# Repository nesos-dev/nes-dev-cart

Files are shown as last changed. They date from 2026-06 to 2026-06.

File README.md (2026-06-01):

# NES-DEV-CART

Open-source FPGA development cartridge for the Nintendo Entertainment System. **v4.1** — now with 8MB onboard PSRAM.

Plugs into a real NES. Programs over USB-C. Debug via UART. Full NES bus access. 39 SMT components, professionally assembled.

## What Is It

NES-DEV-CART is a cartridge-shaped PCB that replaces the ROM chip with a modern FPGA. It gives your FPGA bidirectional access to every signal on the NES 72-pin cartridge connector — CPU bus, PPU bus, CIC, expansion port — all level-shifted between 5V and 3.3V.

An onboard FT2232HL provides USB-C JTAG programming and UART debug console. No external programmer needed.

## Specs

| | |
|---|---|
| **FPGA** | Sipeed Tang Primer 25K (Gowin GW5A-25, 25K LUTs) |
| **ROM Storage** | 8MB SPI PSRAM |
| **USB** | FT2232HL — Ch.A: JTAG, Ch.B: UART debug |
| **Level Shifting** | 4x 74ALVC164245DGG (bidirectional 5V-3.3V) |
| **NES Signals** | CPU A0-A14, D0-D7, PPU A0-A13, D0-D7, CIC, IRQ, EXP |
| **PCB** | 4-layer, 1.6mm, ENIG, gold fingers, L-shaped |
| **Connector** | 72-pin NES edge connector (30-degree bevel) |
| **FPGA Connection** | 2x DF40C-60DS 0.4mm B2B connectors |

## What You Can Build

- **Homebrew games** — test on real hardware, not emulators
- **Custom mappers** — design mapper chips in Verilog that never existed
- **Flash cartridge** — load ROMs from USB, run on real NES
- **Bus analyzer** — sniff CPU/PPU traffic in real time via UART
- **Expansion audio** — VRC6, Sunsoft 5B style audio hardware
- **Hardware research** — study NES bus behavior at the signal level

## Repository Structure

```
hardware/
├── nes-dev-cart.kicad_pcb      KiCad PCB layout
├── nes-dev-cart.kicad_sch      KiCad schematic
├── nes-dev-cart.kicad_pro      KiCad project
├── footprints/                 Custom footprint libraries
├── shell/                     Cart shell STL files (front/back)
└── production/
    ├── nes-dev-cart-gerbers.zip    Fabrication-ready gerbers
    ├── nes-dev-cart-bom.csv        BOM with LCSC part numbers
    ├── nes-dev-cart-cpl-jlcpcb.csv Component placement list
    ├── README-assembly.md          Assembly instructions
    ├── nes-dev-cart-render-*.png   Board renders (top/bottom)
    └── gerbers/                    Individual gerber files

website/                        Product website (nesos.dev)
├── index.html
├── style.css
└── success.html
```

## Ordering PCBs

Upload `hardware/production/nes-dev-cart-gerbers.zip` to JLCPCB:

- Layers: 4
- Thickness: 1.6mm
- Surface finish: ENIG
- Gold fingers: Yes, 30-degree bevel
- Assembly: Both sides (DF40 connectors on bottom)

Upload `nes-dev-cart-bom.csv` and `nes-dev-cart-cpl-jlcpcb.csv` for SMT assembly. See `production/README-assembly.md` for details.

## Requirements

- NES front-loader console (NES-001)
- Sipeed Tang Primer 25K module
- USB-C cable
- Gowin IDE or Yosys/nextpnr for FPGA development

## License

Hardware: GPL-3.0

NES-DEV-CART is an independent project not affiliated with or endorsed by Nintendo.

## Links

- Website: https://nesos.dev

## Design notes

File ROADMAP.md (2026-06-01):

# NES-DEV-CART Roadmap

## Current Status: v4.0 — Hardware Complete

The PCB design is fabrication-ready. Gerbers, BOM, and assembly files are generated. DRC clean.

## v4.1 — SPI PSRAM (In Progress)

Adding 8MB SPI PSRAM for full ROM storage beyond the FPGA's internal block RAM.

### Hardware
- [ ] Add PSRAM to PCB
- [ ] Update gerbers
- [ ] Order prototype PCBs

### FPGA Firmware
- [ ] QSPI PSRAM controller
- [ ] NES bus interface (address decode, tristate data bus)
- [ ] NROM mapper (mapper 0)
- [ ] UxROM mapper (mapper 2)
- [ ] MMC1 mapper (mapper 1)
- [ ] MMC3 mapper (mapper 4)
- [ ] CIC bypass

### Host Software
- [ ] ROM upload via UART
- [ ] Debug console
- [ ] Bus analyzer
- [ ] JTAG programming

### Documentation
- [ ] Hardware pinout reference
- [ ] Signal timing diagrams
- [ ] Mapper development guide

## Timeline

| Milestone | Target |
|---|---|
| v4.1 hardware ordered | June 2026 |
| First game on real NES | July 2026 |
| Host tools + 4 mappers | August 2026 |
| Documentation + launch | September 2026 |

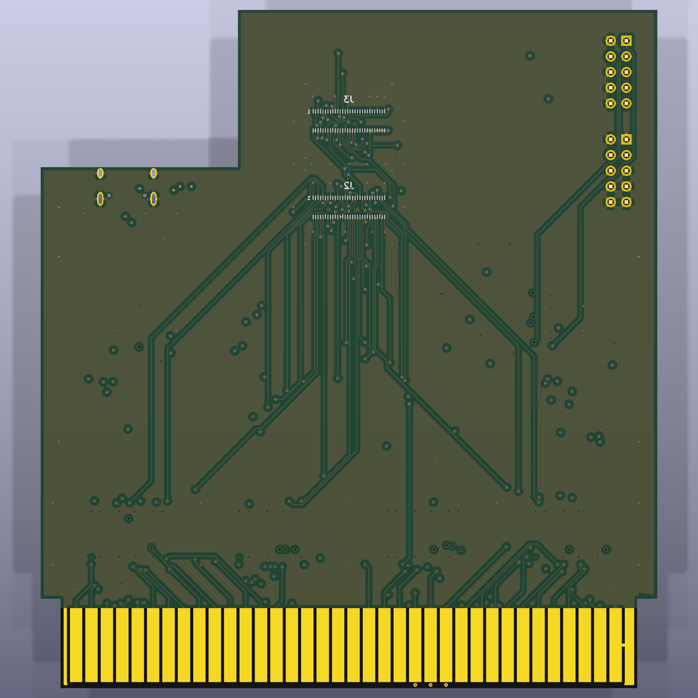
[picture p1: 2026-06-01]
hardware/production/nes-dev-cart-render-bottom.png

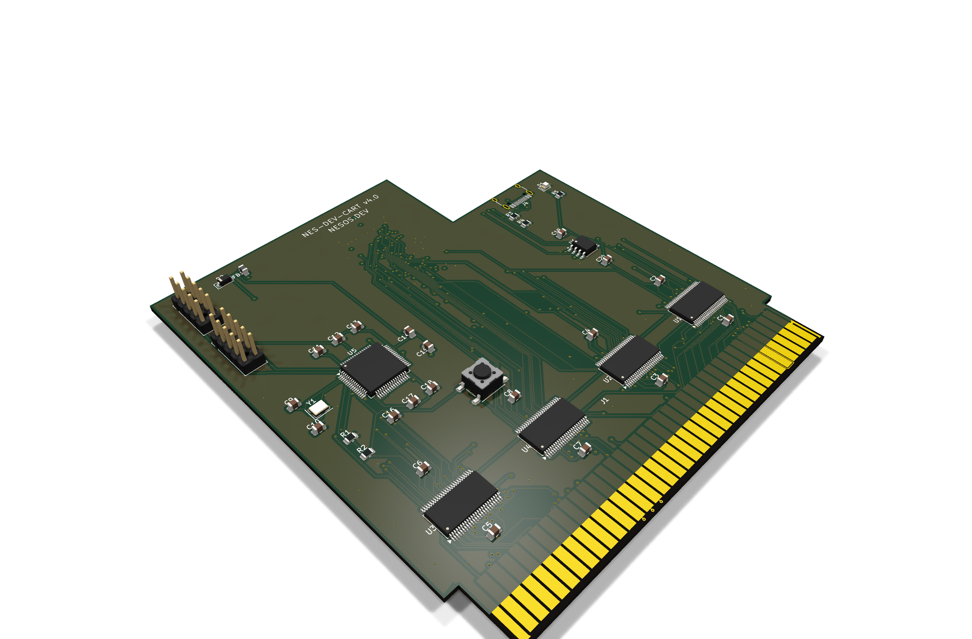
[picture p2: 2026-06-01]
hardware/production/nes-dev-cart-render-top-3d.png

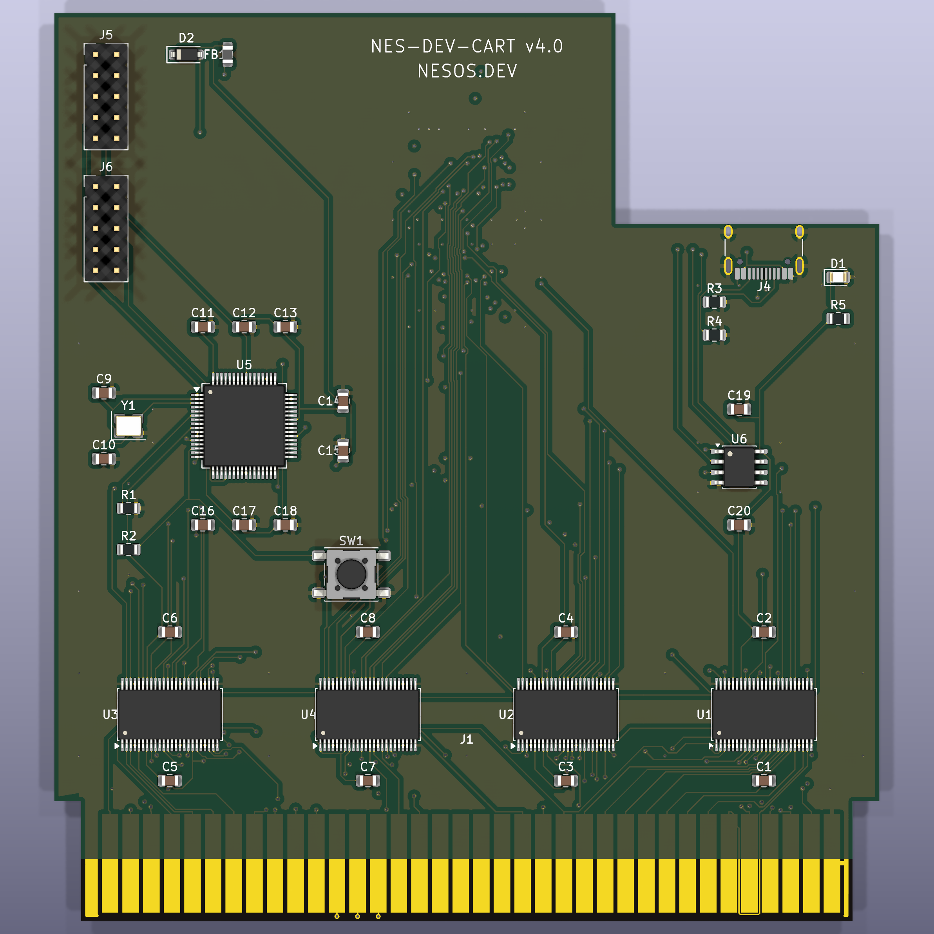
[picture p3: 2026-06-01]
hardware/production/nes-dev-cart-render-top.png

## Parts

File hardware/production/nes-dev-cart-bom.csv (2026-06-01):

Comment | Designator | Footprint | LCSC Part #
100nF 50V X7R | C1,C2,C3,C4,C5,C6,C7,C8,C11,C12,C13,C14,C16,C18,C19 | C_0805_2012Metric | C49678
27pF 50V NP0 | C9,C10 | C_0805_2012Metric | C107113
4.7uF 25V X5R | C15,C17 | C_0805_2012Metric | C1779
2.2k 1% | R1 | R_0805_2012Metric | C17520
10k 1% | R2 | R_0805_2012Metric | C17414
5.1k 1% | R3,R4 | R_0805_2012Metric | C27834
330R 1% | R5 | R_0805_2012Metric | C17630
74ALVC164245DGG | U1,U2,U3,U4 | TSSOP-48_6.1x12.5mm_P0.5mm | C5531
FT2232HL | U5 | LQFP-64_10x10mm_P0.5mm | C27882
12MHz Crystal | Y1 | Crystal_SMD_3225-4Pin_3.2x2.5mm | C390764
Ferrite 600R@100MHz | FB1 | L_0805_2012Metric | C21286
Green LED | D1 | LED_0805_2012Metric | C2297
1N5817W Schottky | D2 | D_SOD-123 | C571353
USB-C 16P Receptacle | J4 | USB_C_Receptacle_HRO_TYPE-C-31-M-12 | C165948
DF40C-60DS-0.4V(51) | J2,J3 | Hirose_DF40C-60DS-0.4V_2x30_P0.4mm | C597938
PTS645SM43SMTR92LFS | SW1 | SW_SPST_PTS645 | C221880
APS6404L-3SQR-SN 8MB PSRAM | U6 | SOIC-8_3.9x4.9mm_P1.27mm | C5333729
10uF 25V X5R | C20 | C_0805_2012Metric | C15850

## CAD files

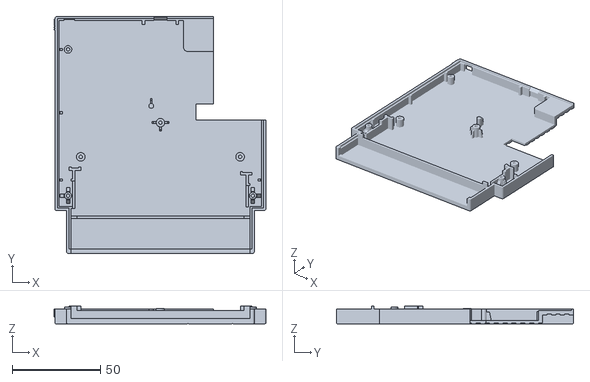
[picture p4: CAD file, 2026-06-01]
hardware/shell/dev_cart_front.stl
119.8 x 134.0 x 10.1

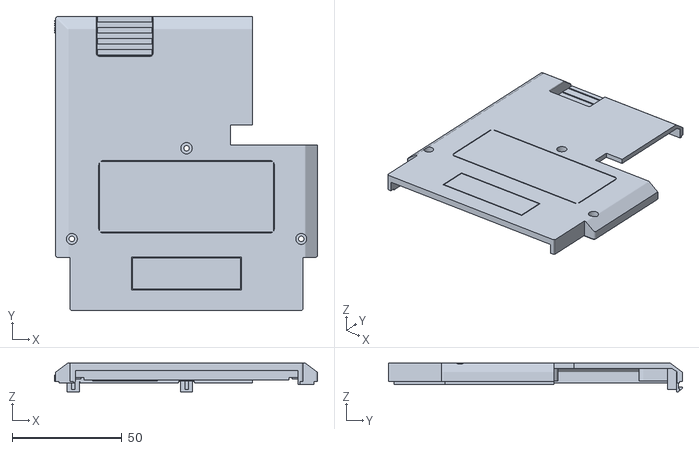
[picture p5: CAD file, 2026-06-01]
hardware/shell/dev_cart_back.stl
119.8 x 134.1 x 13.2

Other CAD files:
hardware/shell/dev_cart_v3.blend

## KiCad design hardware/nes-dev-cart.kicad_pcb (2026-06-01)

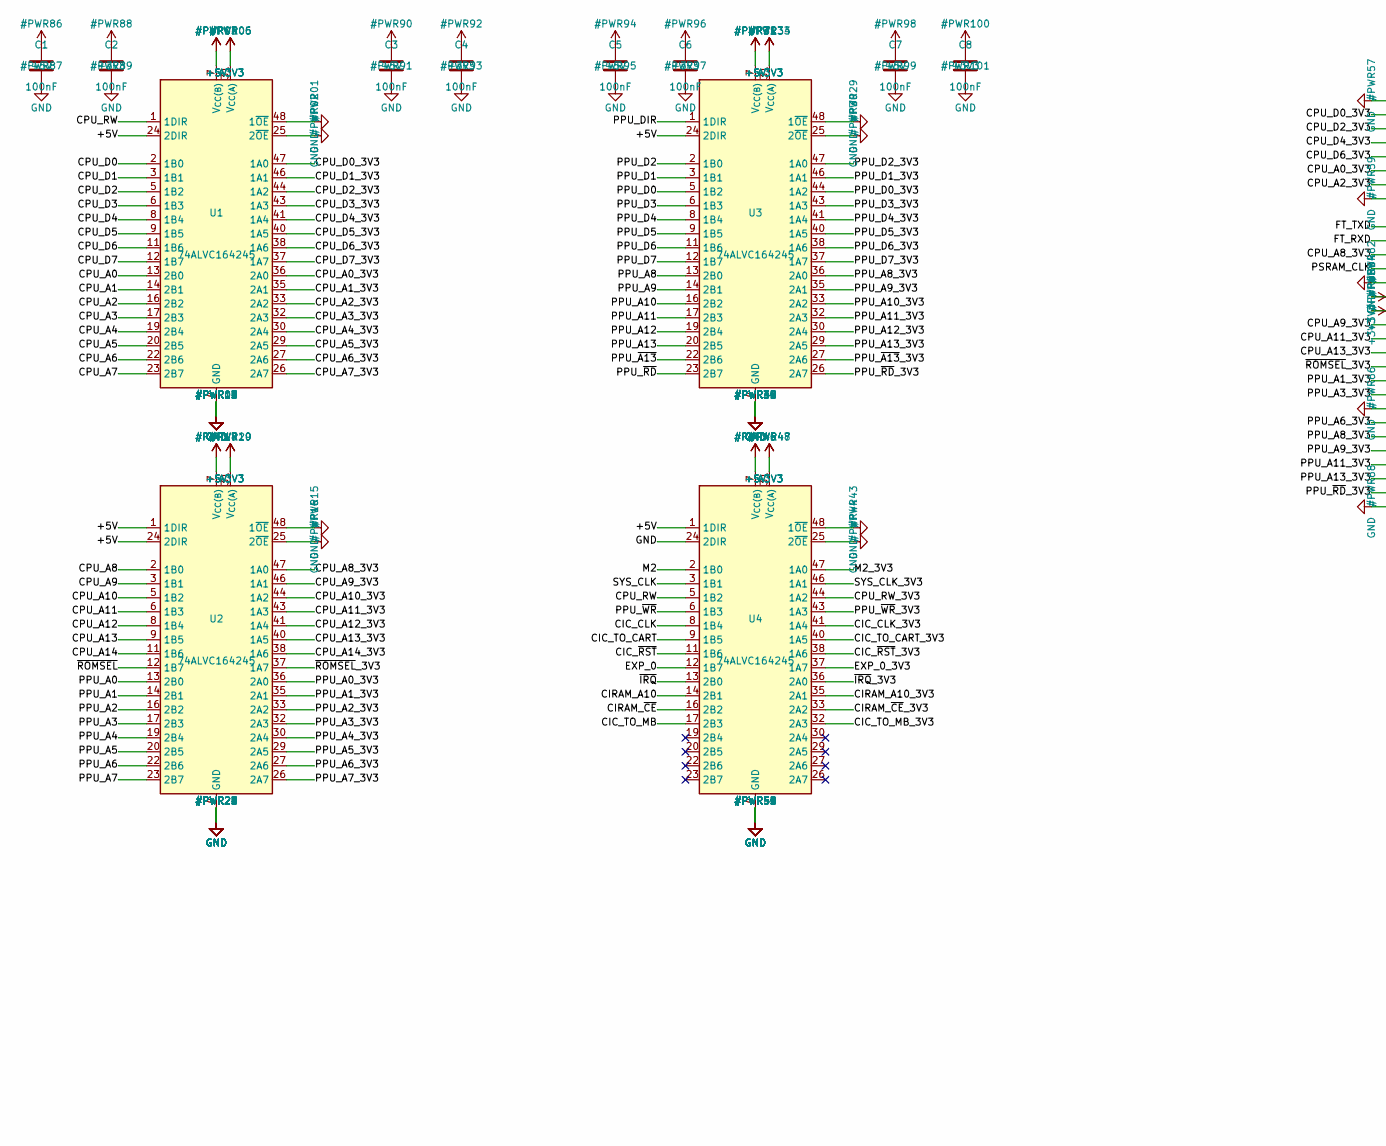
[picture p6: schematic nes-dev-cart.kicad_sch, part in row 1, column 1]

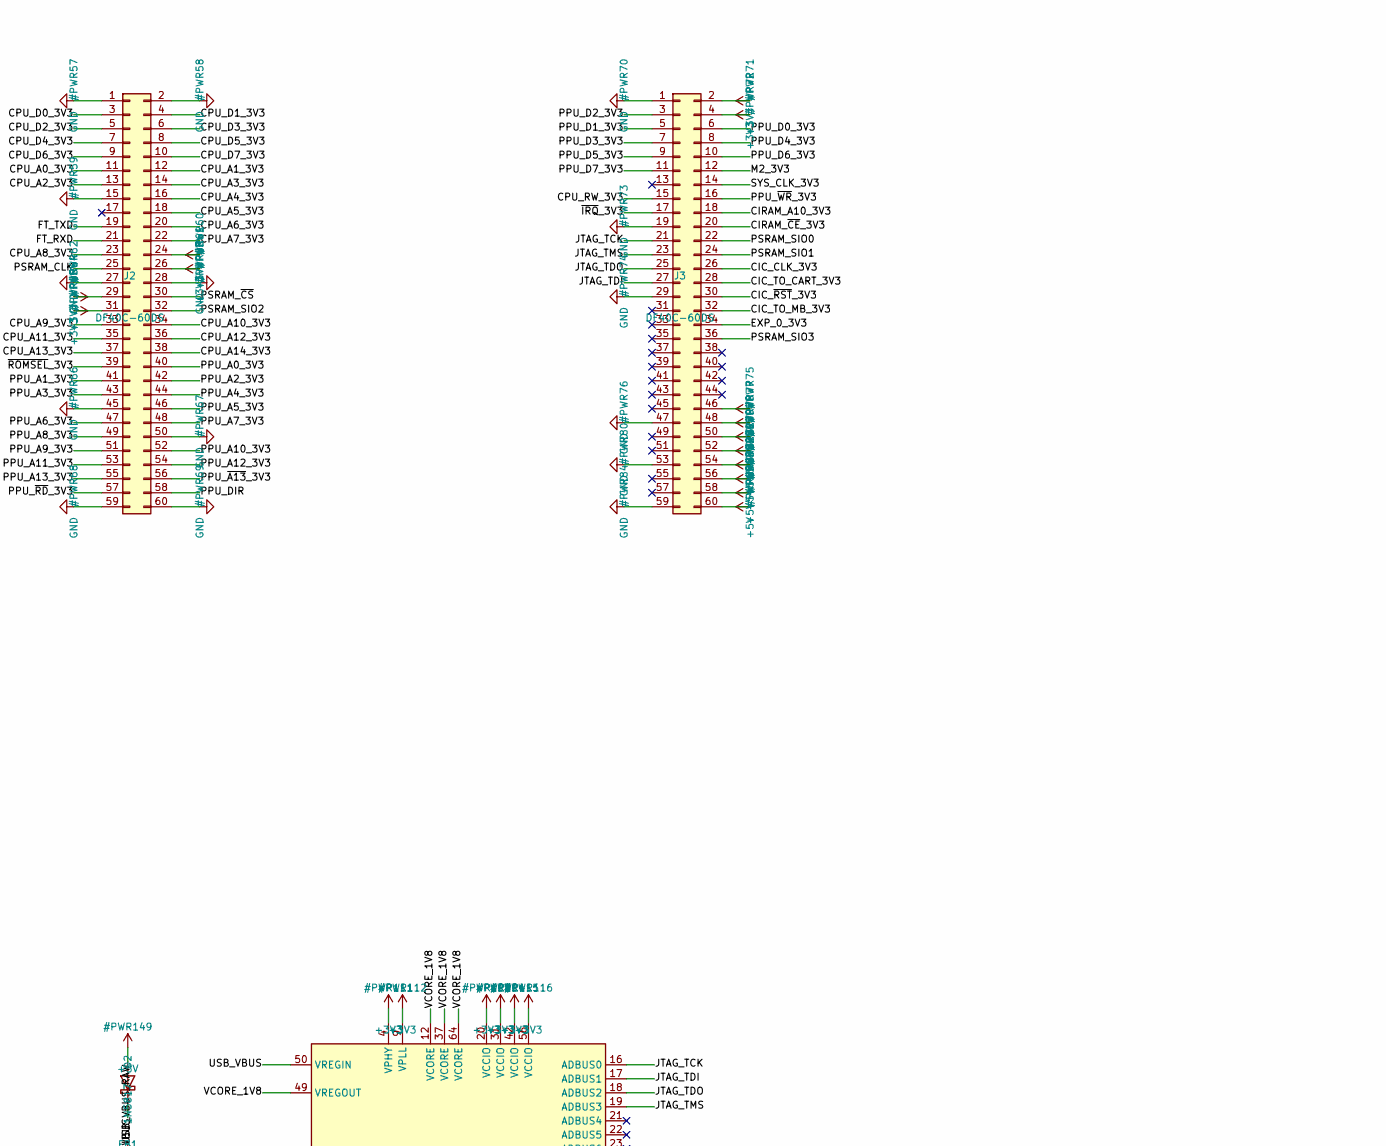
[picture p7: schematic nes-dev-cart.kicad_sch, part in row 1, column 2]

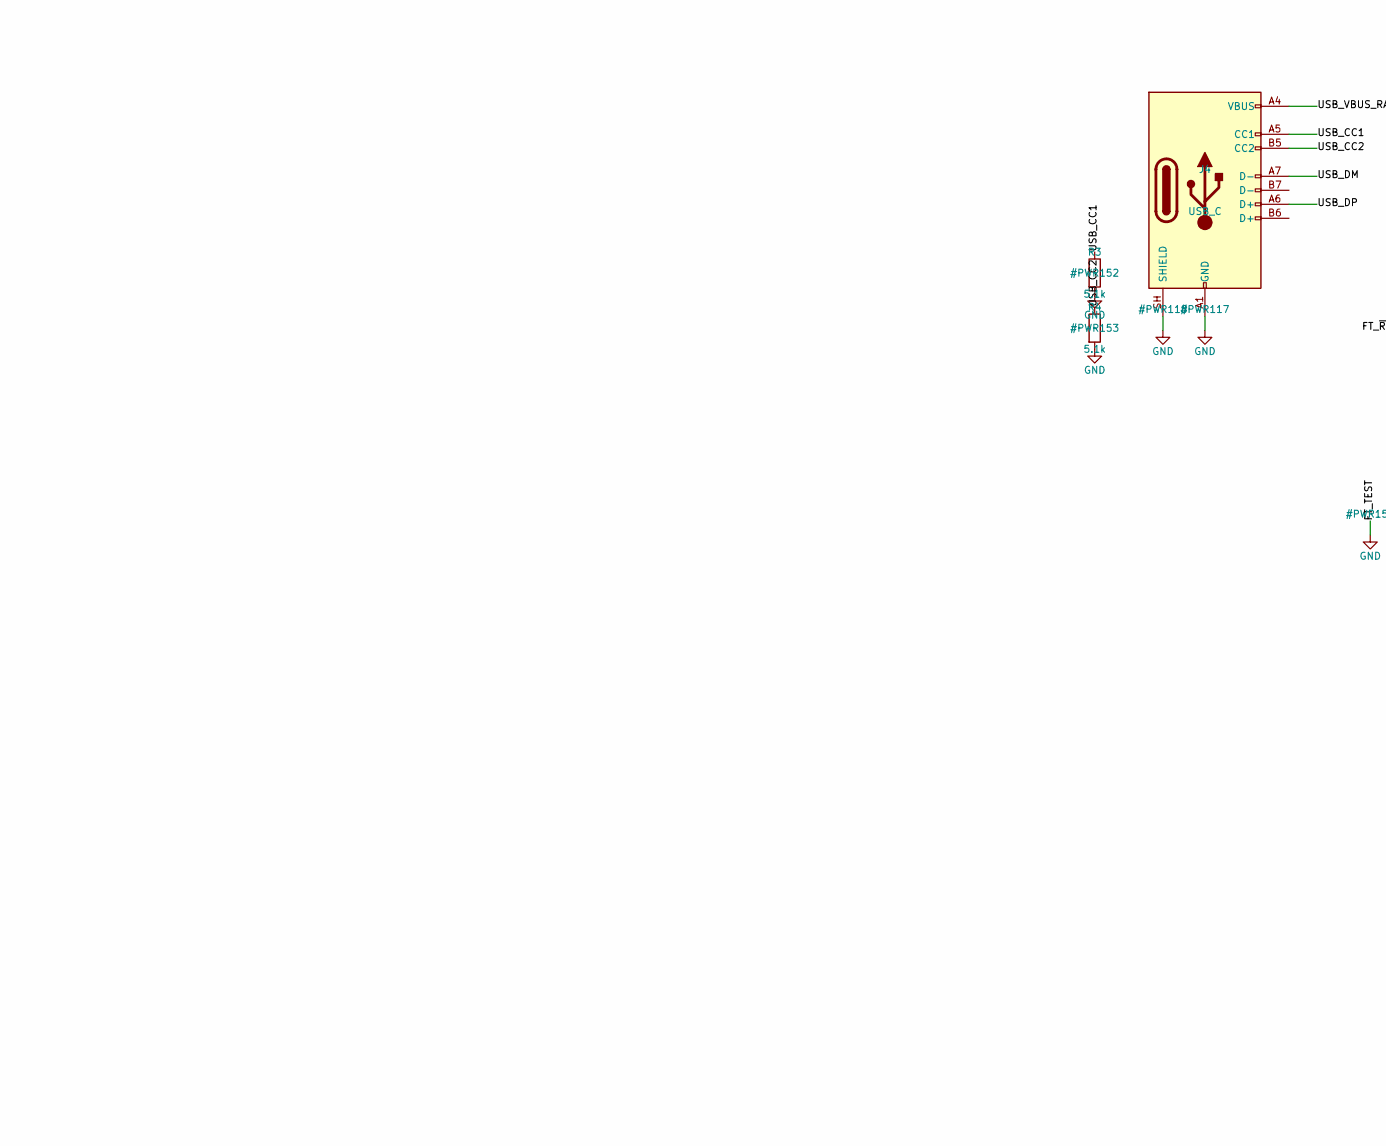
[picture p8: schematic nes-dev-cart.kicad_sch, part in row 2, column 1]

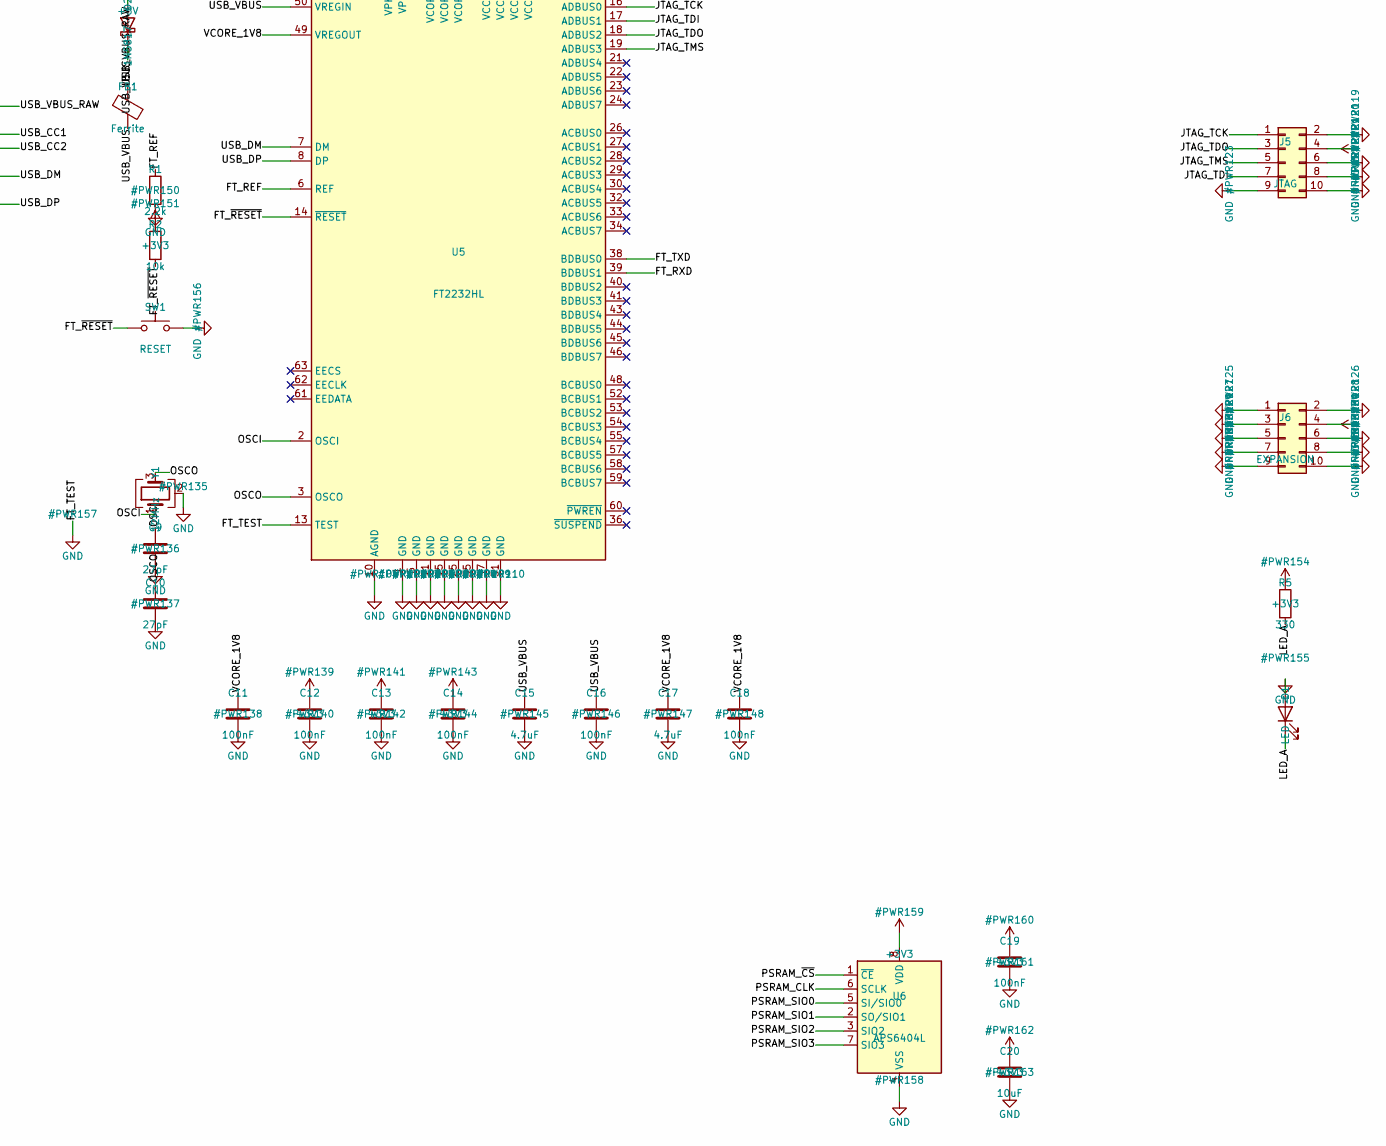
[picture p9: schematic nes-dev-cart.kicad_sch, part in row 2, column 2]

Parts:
C1, C2, C3, C4, C5, C6, C7, C8, C11, C12, C13, C14, C16, C18, C19: 100nF
C9, C10: 27pF
C15, C17: 4.7uF
C20: 10uF
D1: LED
D2: 1N5817
FB1: Ferrite
J2, J3: DF40C-60DS
J4: USB_C
J5: JTAG
J6: EXPANSION
R1: 2.2k
R2: 10k
R3, R4: 5.1k
R5: 330
SW1: RESET
U1, U2, U3, U4: 74ALVC164245
U5: FT2232HL
U6: APS6404L
Y1: 12MHz

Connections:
+3V3: C2.1, C4.1, C6.1, C8.1, C12.1, C13.1, C14.1, C19.1, C20.1, J2.24, J2.26, J2.29, J2.31, J3.2, J3.4, J3.46, J3.48, J3.50, J5.4, J6.4, R2.1, R5.1, U1.31 (V_{CC(A)}), U1.42 (V_{CC(A)}), U2.31 (V_{CC(A)}), U2.42 (V_{CC(A)}), U3.31 (V_{CC(A)}), U3.42 (V_{CC(A)}), U4.31 (V_{CC(A)}), U4.42 (V_{CC(A)}), U5.4 (VPHY), U5.9 (VPLL), U5.20 (VCCIO), U5.31 (VCCIO), U5.42 (VCCIO), U5.56 (VCCIO), U6.8 (VDD)
+5V: C1.1, C3.1, C5.1, C7.1, D2.2 (A), J3.52, J3.54, J3.56, J3.58, J3.60, U1.7 (V_{CC(B)}), U1.18 (V_{CC(B)}), U1.24 (2DIR), U2.1 (1DIR), U2.7 (V_{CC(B)}), U2.18 (V_{CC(B)}), U2.24 (2DIR), U3.7 (V_{CC(B)}), U3.18 (V_{CC(B)}), U3.24 (2DIR), U4.1 (1DIR), U4.7 (V_{CC(B)}), U4.18 (V_{CC(B)}); also elsewhere on the board
/CIC_CLK: U4.8 (1B4); also elsewhere on the board
/CIC_CLK_3V3: J3.26, U4.41 (1A4)
/CIC_TO_CART: U4.9 (1B5); also elsewhere on the board
/CIC_TO_CART_3V3: J3.28, U4.40 (1A5)
/CIC_TO_MB: U4.17 (2B3); also elsewhere on the board
/CIC_TO_MB_3V3: J3.32, U4.32 (2A3)
/CIC_~RST: U4.11 (1B6); also elsewhere on the board
/CIC_~RST_3V3: J3.30, U4.38 (1A6)
/CIRAM_A10: U4.14 (2B1); also elsewhere on the board
/CIRAM_A10_3V3: J3.18, U4.35 (2A1)
/CIRAM_~CE: U4.16 (2B2); also elsewhere on the board
/CIRAM_~CE_3V3: J3.20, U4.33 (2A2)
/CPU_A0: U1.13 (2B0); also elsewhere on the board
/CPU_A0_3V3: J2.11, U1.36 (2A0)
/CPU_A1: U1.14 (2B1); also elsewhere on the board
/CPU_A1_3V3: J2.12, U1.35 (2A1)
/CPU_A2: U1.16 (2B2); also elsewhere on the board
/CPU_A2_3V3: J2.13, U1.33 (2A2)
/CPU_A3: U1.17 (2B3); also elsewhere on the board
/CPU_A3_3V3: J2.14, U1.32 (2A3)
/CPU_A4: U1.19 (2B4); also elsewhere on the board
/CPU_A4_3V3: J2.16, U1.30 (2A4)
/CPU_A5: U1.20 (2B5); also elsewhere on the board
/CPU_A5_3V3: J2.18, U1.29 (2A5)
/CPU_A6: U1.22 (2B6); also elsewhere on the board
/CPU_A6_3V3: J2.20, U1.27 (2A6)
/CPU_A7: U1.23 (2B7); also elsewhere on the board
/CPU_A7_3V3: J2.22, U1.26 (2A7)
/CPU_A8: U2.2 (1B0); also elsewhere on the board
/CPU_A8_3V3: J2.23, U2.47 (1A0)
/CPU_A9: U2.3 (1B1); also elsewhere on the board
/CPU_A9_3V3: J2.33, U2.46 (1A1)
/CPU_A10: U2.5 (1B2); also elsewhere on the board
/CPU_A10_3V3: J2.34, U2.44 (1A2)
/CPU_A11: U2.6 (1B3); also elsewhere on the board
/CPU_A11_3V3: J2.35, U2.43 (1A3)
/CPU_A12: U2.8 (1B4); also elsewhere on the board
/CPU_A12_3V3: J2.36, U2.41 (1A4)
/CPU_A13: U2.9 (1B5); also elsewhere on the board
/CPU_A13_3V3: J2.37, U2.40 (1A5)
/CPU_A14: U2.11 (1B6); also elsewhere on the board
/CPU_A14_3V3: J2.38, U2.38 (1A6)
/CPU_D0: U1.2 (1B0); also elsewhere on the board
/CPU_D0_3V3: J2.3, U1.47 (1A0)
/CPU_D1: U1.3 (1B1); also elsewhere on the board
/CPU_D1_3V3: J2.4, U1.46 (1A1)
/CPU_D2: U1.5 (1B2); also elsewhere on the board
/CPU_D2_3V3: J2.5, U1.44 (1A2)
/CPU_D3: U1.6 (1B3); also elsewhere on the board
/CPU_D3_3V3: J2.6, U1.43 (1A3)
/CPU_D4: U1.8 (1B4); also elsewhere on the board
/CPU_D4_3V3: J2.7, U1.41 (1A4)
/CPU_D5: U1.9 (1B5); also elsewhere on the board
/CPU_D5_3V3: J2.8, U1.40 (1A5)
/CPU_D6: U1.11 (1B6); also elsewhere on the board
/CPU_D6_3V3: J2.9, U1.38 (1A6)
/CPU_D7: U1.12 (1B7); also elsewhere on the board
/CPU_D7_3V3: J2.10, U1.37 (1A7)
/CPU_RW: U1.1 (1DIR), U4.5 (1B2); also elsewhere on the board
/CPU_RW_3V3: J3.15, U4.44 (1A2)
/EXP_0: U4.12 (1B7); also elsewhere on the board
/EXP_0_3V3: J3.34, U4.37 (1A7)
/FT_REF: R1.1, U5.6 (REF)
/FT_RXD: J2.21, U5.39 (BDBUS1)
/FT_TXD: J2.19, U5.38 (BDBUS0)
/FT_~RESET: R2.2, SW1.1, U5.14 (~RESET)
/JTAG_TCK: J3.21, J5.1, U5.16 (ADBUS0)
/JTAG_TDI: J3.27, J5.7, U5.17 (ADBUS1)
/JTAG_TDO: J3.25, J5.3, U5.18 (ADBUS2)
/JTAG_TMS: J3.23, J5.5, U5.19 (ADBUS3)
/LED_A: D1.1 (K), R5.2
/M2: U4.2 (1B0); also elsewhere on the board
/M2_3V3: J3.12, U4.47 (1A0)
/OSCI: C9.1, U5.2 (OSCI), Y1.1
/OSCO: C10.1, U5.3 (OSCO), Y1.3
/PPU_A0: U2.13 (2B0); also elsewhere on the board
/PPU_A0_3V3: J2.40, U2.36 (2A0)
/PPU_A1: U2.14 (2B1); also elsewhere on the board
/PPU_A1_3V3: J2.41, U2.35 (2A1)
/PPU_A2: U2.16 (2B2); also elsewhere on the board
/PPU_A2_3V3: J2.42, U2.33 (2A2)
/PPU_A3: U2.17 (2B3); also elsewhere on the board
/PPU_A3_3V3: J2.43, U2.32 (2A3)
/PPU_A4: U2.19 (2B4); also elsewhere on the board
/PPU_A4_3V3: J2.44, U2.30 (2A4)
/PPU_A5: U2.20 (2B5); also elsewhere on the board
/PPU_A5_3V3: J2.46, U2.29 (2A5)
/PPU_A6: U2.22 (2B6); also elsewhere on the board
/PPU_A6_3V3: J2.47, U2.27 (2A6)
/PPU_A7: U2.23 (2B7); also elsewhere on the board
/PPU_A7_3V3: J2.48, U2.26 (2A7)
/PPU_A8: U3.13 (2B0); also elsewhere on the board
/PPU_A8_3V3: J2.49, U3.36 (2A0)
/PPU_A9: U3.14 (2B1); also elsewhere on the board
/PPU_A9_3V3: J2.51, U3.35 (2A1)
/PPU_A10: U3.16 (2B2); also elsewhere on the board
/PPU_A10_3V3: J2.52, U3.33 (2A2)
/PPU_A11: U3.17 (2B3); also elsewhere on the board
/PPU_A11_3V3: J2.53, U3.32 (2A3)
/PPU_A12: U3.19 (2B4); also elsewhere on the board
/PPU_A12_3V3: J2.54, U3.30 (2A4)
/PPU_A13: U3.20 (2B5); also elsewhere on the board
/PPU_A13_3V3: J2.55, U3.29 (2A5)
/PPU_D0: U3.5 (1B2); also elsewhere on the board
/PPU_D0_3V3: J3.6, U3.44 (1A2)
/PPU_D1: U3.3 (1B1); also elsewhere on the board
/PPU_D1_3V3: J3.5, U3.46 (1A1)
/PPU_D2: U3.2 (1B0); also elsewhere on the board
/PPU_D2_3V3: J3.3, U3.47 (1A0)
/PPU_D3: U3.6 (1B3); also elsewhere on the board
/PPU_D3_3V3: J3.7, U3.43 (1A3)
/PPU_D4: U3.8 (1B4); also elsewhere on the board
/PPU_D4_3V3: J3.8, U3.41 (1A4)
/PPU_D5: U3.9 (1B5); also elsewhere on the board
/PPU_D5_3V3: J3.9, U3.40 (1A5)
/PPU_D6: U3.11 (1B6); also elsewhere on the board
/PPU_D6_3V3: J3.10, U3.38 (1A6)
/PPU_D7: U3.12 (1B7); also elsewhere on the board
/PPU_D7_3V3: J3.11, U3.37 (1A7)
/PPU_DIR: J2.58, U3.1 (1DIR)
/PPU_~A13: U3.22 (2B6); also elsewhere on the board
/PPU_~A13_3V3: J2.56, U3.27 (2A6)
/PPU_~RD: U3.23 (2B7); also elsewhere on the board
/PPU_~RD_3V3: J2.57, U3.26 (2A7)
/PPU_~WR: U4.6 (1B3); also elsewhere on the board
/PPU_~WR_3V3: J3.16, U4.43 (1A3)
/PSRAM_CLK: J2.25, U6.6 (SCLK)
/PSRAM_SIO0: J3.22, U6.5 (SI/SIO0)
/PSRAM_SIO1: J3.24, U6.2 (SO/SIO1)
/PSRAM_SIO2: J2.32, U6.3 (SIO2)
/PSRAM_SIO3: J3.36, U6.7 (SIO3)
/PSRAM_~CS: J2.30, U6.1 (~CE)
/SYS_CLK: U4.3 (1B1); also elsewhere on the board
/SYS_CLK_3V3: J3.14, U4.46 (1A1)
/USB_CC1: J4.A5 (CC1), R3.1
/USB_CC2: J4.B5 (CC2), R4.1
/USB_DM: J4.A7 (D-), U5.7 (DM)
/USB_DP: J4.A6 (D+), U5.8 (DP)
/USB_VBUS: C15.1, C16.1, D2.1 (K), FB1.2, U5.50 (VREGIN)
/USB_VBUS_RAW: FB1.1, J4.A4 (VBUS), J4.A9 (VBUS), J4.B4 (VBUS), J4.B9 (VBUS)
/VCORE_1V8: C11.1, C17.1, C18.1, U5.12 (VCORE), U5.37 (VCORE), U5.49 (VREGOUT), U5.64 (VCORE)
/~IRQ: U4.13 (2B0); also elsewhere on the board
/~IRQ_3V3: J3.17, U4.36 (2A0)
/~ROMSEL: U2.12 (1B7); also elsewhere on the board
/~ROMSEL_3V3: J2.39, U2.37 (1A7)
GND: C1.2, C2.2, C3.2, C4.2, C5.2, C6.2, C7.2, C8.2, C9.2, C10.2, C11.2, C12.2, C13.2, C14.2, C15.2, C16.2, C17.2, C18.2, C19.2, C20.2, D1.2 (A), J2.1, J2.2, J2.15, J2.27, J2.28, J2.45, J2.50, J2.59, J2.60, J3.1, J3.19, J3.29, J3.47, J3.53, J3.59, J4.A1 (GND), J4.A12 (GND), J4.B1 (GND), J4.B12 (GND), J4.SH (SHIELD), J5.2, J5.6, J5.8, J5.9, J5.10, J6.1, J6.2, J6.3, J6.5, J6.6, J6.7, J6.8, J6.9, J6.10, R1.2, R3.2, R4.2, SW1.2, U1.4 (GND), U1.10 (GND), U1.15 (GND), U1.21 (GND), U1.25 (2~OE), U1.28 (GND), U1.34 (GND), U1.39 (GND), U1.45 (GND), U1.48 (1~OE), U2.4 (GND), U2.10 (GND), U2.15 (GND), U2.21 (GND), U2.25 (2~OE), U2.28 (GND), U2.34 (GND), U2.39 (GND), U2.45 (GND), U2.48 (1~OE), U3.4 (GND), U3.10 (GND), U3.15 (GND), U3.21 (GND), U3.25 (2~OE), U3.28 (GND), U3.34 (GND), U3.39 (GND), U3.45 (GND), U3.48 (1~OE), U4.4 (GND), U4.10 (GND), U4.15 (GND), U4.21 (GND), U4.24 (2DIR), U4.25 (2~OE), U4.28 (GND), U4.34 (GND), U4.39 (GND), U4.45 (GND), U4.48 (1~OE), U5.1 (GND), U5.5 (GND), U5.10 (AGND), U5.11 (GND), U5.13 (TEST), U5.15 (GND), U5.25 (GND), U5.35 (GND), U5.47 (GND), U5.51 (GND), U6.4 (VSS), Y1.2 (G), Y1.4 (G); also elsewhere on the board

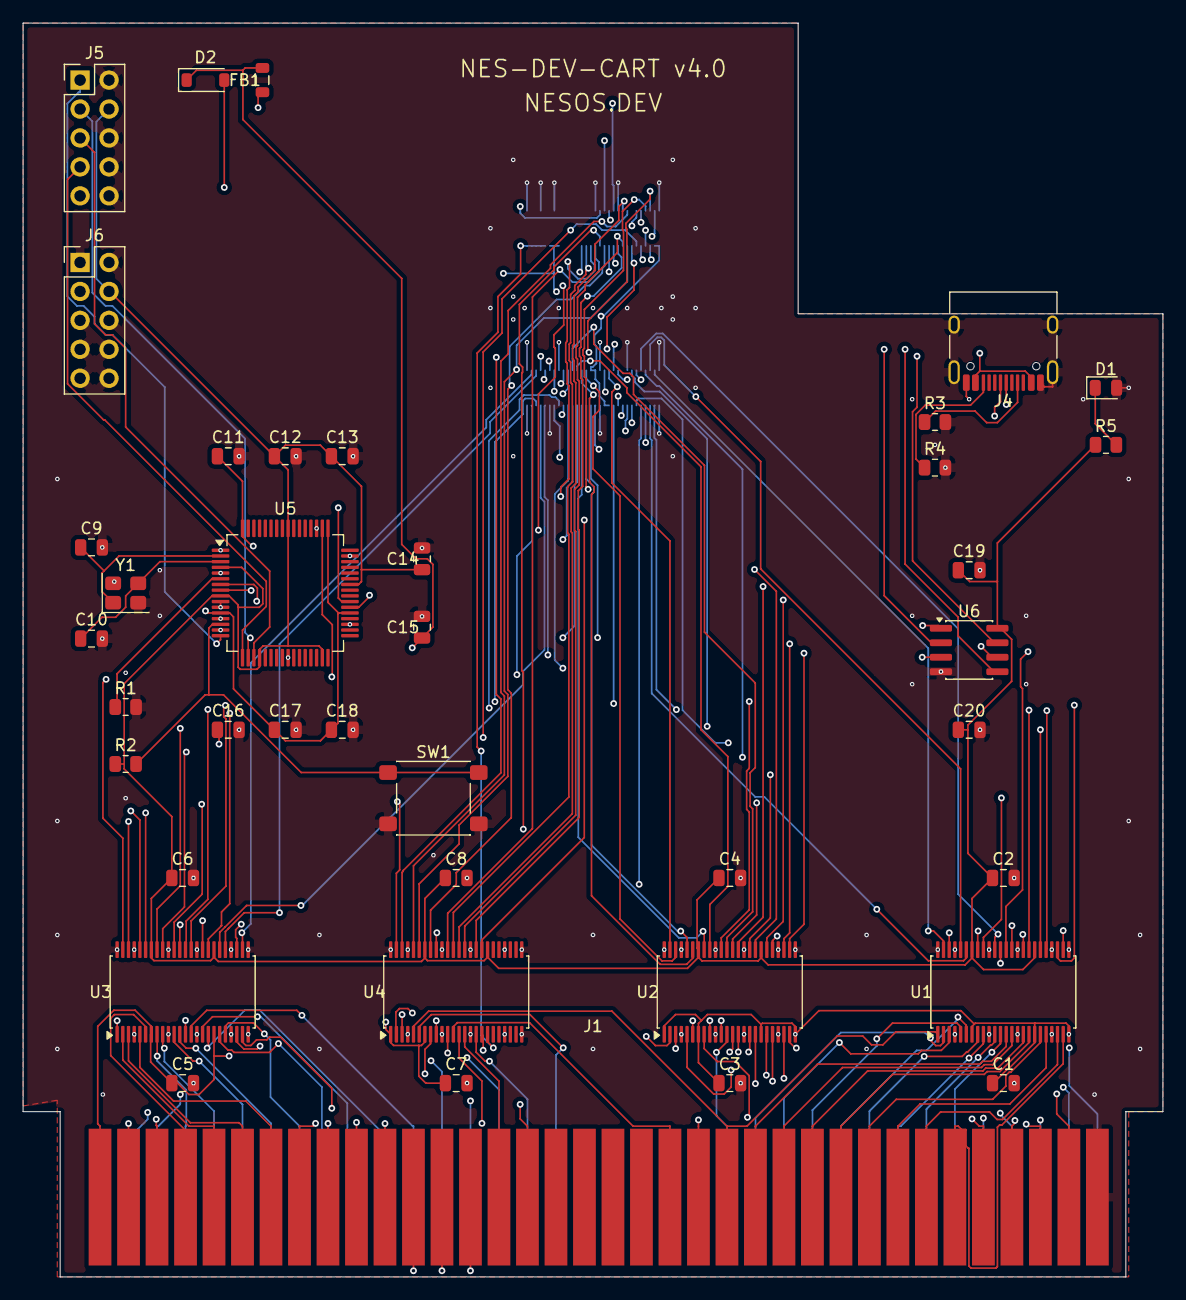
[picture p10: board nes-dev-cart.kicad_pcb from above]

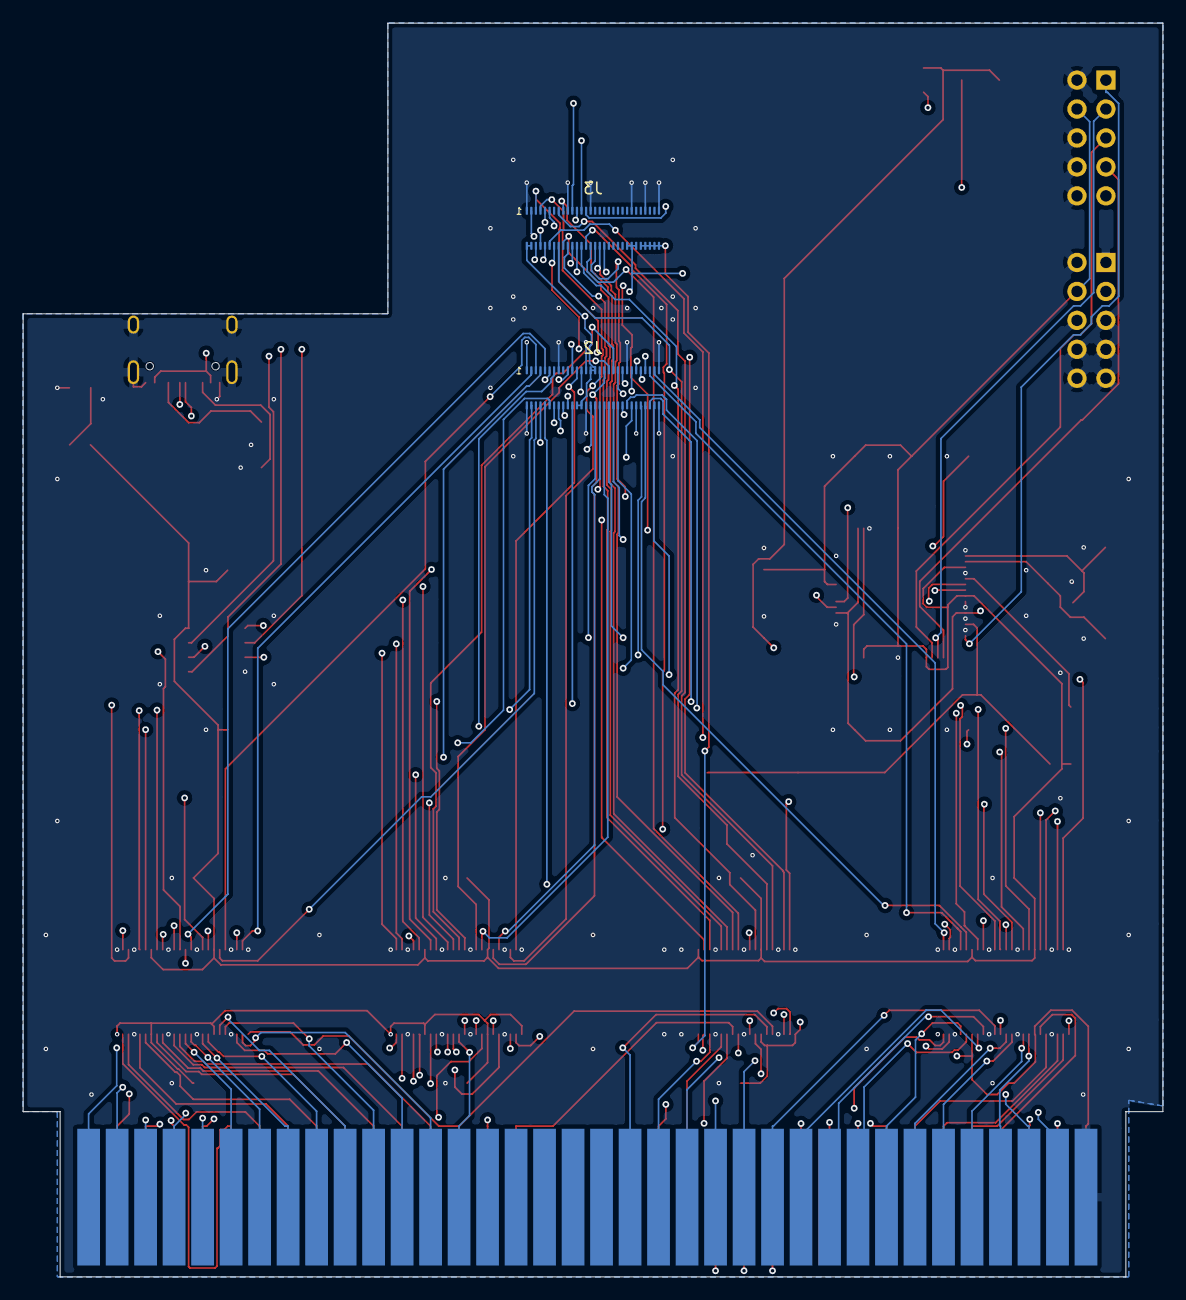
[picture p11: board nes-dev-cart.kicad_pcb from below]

Board: 4 copper layers, 100.0 x 110.0 mm, 42 parts (2 on the bottom side), 148 nets.

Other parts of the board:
J1: NES_72Pin; NES_72Pin_CardEdge

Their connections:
+5V: J1.36; also elsewhere on the board
/CIC_CLK: J1.70; also elsewhere on the board
/CIC_TO_CART: J1.34; also elsewhere on the board
/CIC_TO_MB: J1.35; also elsewhere on the board
/CIC_~RST: J1.71; also elsewhere on the board
/CIRAM_A10: J1.22; also elsewhere on the board
/CIRAM_~CE: J1.57; also elsewhere on the board
/CPU_A0: J1.13; also elsewhere on the board
/CPU_A1: J1.12; also elsewhere on the board
/CPU_A2: J1.11; also elsewhere on the board
/CPU_A3: J1.10; also elsewhere on the board
/CPU_A4: J1.9; also elsewhere on the board
/CPU_A5: J1.8; also elsewhere on the board
/CPU_A6: J1.7; also elsewhere on the board
/CPU_A7: J1.6; also elsewhere on the board
/CPU_A8: J1.5; also elsewhere on the board
/CPU_A9: J1.4; also elsewhere on the board
/CPU_A10: J1.3; also elsewhere on the board
/CPU_A11: J1.2; also elsewhere on the board
/CPU_A12: J1.39; also elsewhere on the board
/CPU_A13: J1.40; also elsewhere on the board
/CPU_A14: J1.41; also elsewhere on the board
/CPU_D0: J1.49; also elsewhere on the board
/CPU_D1: J1.48; also elsewhere on the board
/CPU_D2: J1.47; also elsewhere on the board
/CPU_D3: J1.46; also elsewhere on the board
/CPU_D4: J1.45; also elsewhere on the board
/CPU_D5: J1.44; also elsewhere on the board
/CPU_D6: J1.43; also elsewhere on the board
/CPU_D7: J1.42; also elsewhere on the board
/CPU_RW: J1.14; also elsewhere on the board
/EXP_0: J1.16; also elsewhere on the board
/M2: J1.38; also elsewhere on the board
/PPU_A0: J1.29; also elsewhere on the board
/PPU_A1: J1.28; also elsewhere on the board
/PPU_A2: J1.27; also elsewhere on the board
/PPU_A3: J1.26; also elsewhere on the board
/PPU_A4: J1.25; also elsewhere on the board
/PPU_A5: J1.24; also elsewhere on the board
/PPU_A6: J1.23; also elsewhere on the board
/PPU_A7: J1.59; also elsewhere on the board
/PPU_A8: J1.60; also elsewhere on the board
/PPU_A9: J1.61; also elsewhere on the board
/PPU_A10: J1.63; also elsewhere on the board
/PPU_A11: J1.62; also elsewhere on the board
/PPU_A12: J1.64; also elsewhere on the board
/PPU_A13: J1.65; also elsewhere on the board
/PPU_D0: J1.30; also elsewhere on the board
/PPU_D1: J1.31; also elsewhere on the board
/PPU_D2: J1.32; also elsewhere on the board
/PPU_D3: J1.33; also elsewhere on the board
/PPU_D4: J1.69; also elsewhere on the board
/PPU_D5: J1.68; also elsewhere on the board
/PPU_D6: J1.67; also elsewhere on the board
/PPU_D7: J1.66; also elsewhere on the board
/PPU_~A13: J1.58; also elsewhere on the board
/PPU_~RD: J1.21; also elsewhere on the board
/PPU_~WR: J1.56; also elsewhere on the board
/SYS_CLK: J1.37; also elsewhere on the board
/~IRQ: J1.15; also elsewhere on the board
/~ROMSEL: J1.50; also elsewhere on the board
GND: J1.1, J1.72; also elsewhere on the board

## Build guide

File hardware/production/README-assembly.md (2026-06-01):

# NES-DEV-CART v4.1 — JLCPCB Production & Assembly

## Board Specifications

| Parameter | Value |
|---|---|
| Layers | 4 |
| Thickness | 1.6mm |
| Finish | ENIG (required for edge connector) |
| Min trace/space | 0.15mm / 0.15mm |
| Min via | 0.4mm pad / 0.2mm drill |
| Board dimensions | 100mm x 110mm (L-shaped) |
| Edge connector | Bevelled, 30-degree, bottom side |

## JLCPCB Order Settings

- **PCB**: Upload `nes-dev-cart-gerbers.zip`
- **Layers**: 4
- **PCB Thickness**: 1.6mm
- **Surface Finish**: ENIG
- **Gold Fingers**: Yes, 30-degree bevel
- **Remove Order Number**: Specify location or "Yes"

## SMT Assembly

### Assembly Type: Both Sides

- **Top side**: 36 components (passives, ICs, USB-C, crystal, LED, switch, PSRAM)
- **Bottom side**: 2 components (DF40 B2B connectors)
- **Total**: 38 SMT assembled (+ 1 card edge connector = 39 SMT pads on BOM)

### Files to Upload

| File | Purpose |
|---|---|
| `nes-dev-cart-bom.csv` | Bill of Materials with LCSC part numbers |
| `nes-dev-cart-cpl-jlcpcb.csv` | Component Placement List (pick & place) |

### Component Summary (39 SMT parts)

| Qty | Designator | Part | LCSC | Notes |
|-----|---|---|---|---|
| 15 | C1-C8,C11-C14,C16,C18,C19 | 100nF 0805 X7R | C49678 | Basic part |
| 2 | C9,C10 | 27pF 0805 NP0 | C107113 | Crystal load caps |
| 2 | C15,C17 | 4.7uF 0805 X5R | C1779 | Basic part |
| 1 | R1 | 2.2k 0805 | C17520 | Basic part |
| 1 | R2 | 10k 0805 | C17414 | Basic part |
| 2 | R3,R4 | 5.1k 0805 | C27834 | USB-C CC pull-downs |
| 1 | R5 | 330R 0805 | C17630 | LED current limit |
| 4 | U1-U4 | 74ALVC164245DGG TSSOP-48 | C5531 | Level shifters |
| 1 | U5 | FT2232HL LQFP-64 | C27882 | USB-JTAG/UART |
| 1 | Y1 | 12MHz 3225 crystal | C390764 | FT2232HL clock |
| 1 | FB1 | Ferrite 600R 0805 | C21286 | USB VBUS filter |
| 1 | D1 | Green LED 0805 | C2297 | Power indicator |
| 1 | D2 | 1N5817W SOD-123 | C571353 | Power OR diode |
| 1 | J4 | USB-C HRO TYPE-C-31-M-12 | C165948 | USB connector |
| 2 | J2,J3 | DF40C-60DS-0.4V(51) | C597938 | B2B receptacles (BOTTOM) |
| 1 | SW1 | PTS645SM43SMTR92LFS | C221880 | Reset button |
| 1 | U6 | APS6404L-3SQR-SN SOIC-8 | C5333729 | 8MB SPI PSRAM |
| 1 | C20 | 10uF 0805 X5R | C15850 | PSRAM bulk decoupling |

### NOT Assembled by JLCPCB (hand-solder)

| Designator | Part | Notes |
|---|---|---|
| J5 | 2x5 pin header 2.54mm | JTAG — solder after SMT |
| J6 | 2x5 pin header 2.54mm | Expansion power header — solder after SMT |
| J1 | — | Card edge connector (no component, part of PCB) |

### Rotation Check

JLCPCB may apply rotation offsets during review. Verify orientation of:
- U1-U4 (TSSOP-48 at 90 degrees — pin 1 dot should face left)
- U5 (LQFP-64 — pin 1 dot at top-left)
- J4 (USB-C — opening faces board edge at Y=85.5)
- J2,J3 (DF40 — pin 1 at left side)
- D2 (SOD-123 — cathode band orientation)

## Post-Assembly

1. **Visual inspection** under magnification — check DF40 solder joints especially
2. **Solder J5, J6** pin headers by hand
3. **Plug in Tang Primer 25K** via DF40 connectors
4. **Connect USB-C** and verify FT2232HL enumerates (should appear as dual serial port)
5. **Program FPGA** via JTAG header or FT2232HL

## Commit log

2026-06-01 NES-DEV-CART v4.0: hardware design files and production outputs
    [nes-dev-cart-B_Cu.gbl, nes-dev-cart-B_Mask.gbs, nes-dev-cart-B_Paste.gbp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]
2026-06-01 NES-DEV-CART v4.1: 8MB PSRAM, updated production files, website
    - Updated KiCad PCB/schematic with 8MB SPI PSRAM (APS6404L)
    - Regenerated gerbers, BOM, and CPL for v4.1
    - Added product website (nesos.dev)
    - Updated README with v4.1 specs
    - Added GitHub link to website footer
    [nes-dev-cart-B_Cu.gbl, nes-dev-cart-B_Mask.gbs, nes-dev-cart-B_Paste.gbp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]
2026-06-01 v4.1: KiCad 3D renders, cart shell STLs, website pricing update
    - 4 high-quality KiCad raytraced board renders (top/bottom, ortho/perspective)
    - Cart shell STL files (front and back halves)
    - Website: two-tier pricing ($100 early bird, $120 standard)
    - Updated repo structure with shell/ directory
    [dev_cart_back.stl, dev_cart_front.stl]
2026-06-01 Cart shell v3: L-notch for USB-C cable access
    Modified NES-001 cart shell with L-shaped notch in upper-right
    for USB-C cable access. Based on third-party authentic NES shell.
    [dev_cart_back.stl, dev_cart_front.stl, dev_cart_v3.blend]
